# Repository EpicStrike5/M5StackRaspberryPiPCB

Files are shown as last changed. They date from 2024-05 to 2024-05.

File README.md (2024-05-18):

# M5StackRaspberryPiPCB
A simple dev board for using decentralized I/O port from the both of them 

I created this PCB for the sole purpose of decentralizing the I/O port for both the M5Stack Gray and the Raspberry Pi4. The intent is that it's easier to develop on a breadboard with a "fixed" Pi or M5. 

The gist is that we have female header and we decide to populate half of the pin holes ith header. In the case of a 1x2 Header, we solder a 1P header and leaves one hole free so that we can plug rigid cable if we don't want to use jumpers.

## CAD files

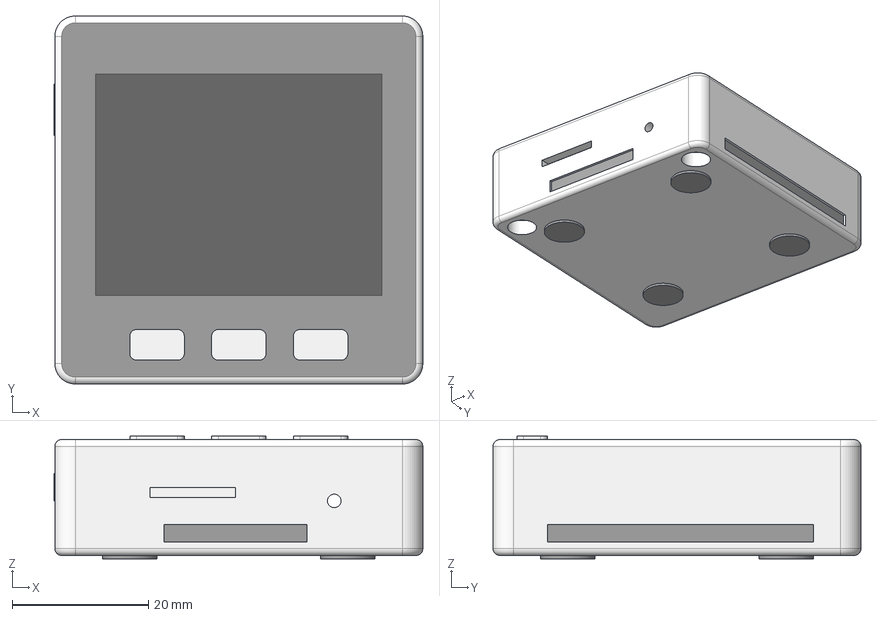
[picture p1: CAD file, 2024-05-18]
Librairie/M5Stack/M5Stack.stp
54.1 x 54.0 x 18.0 mm

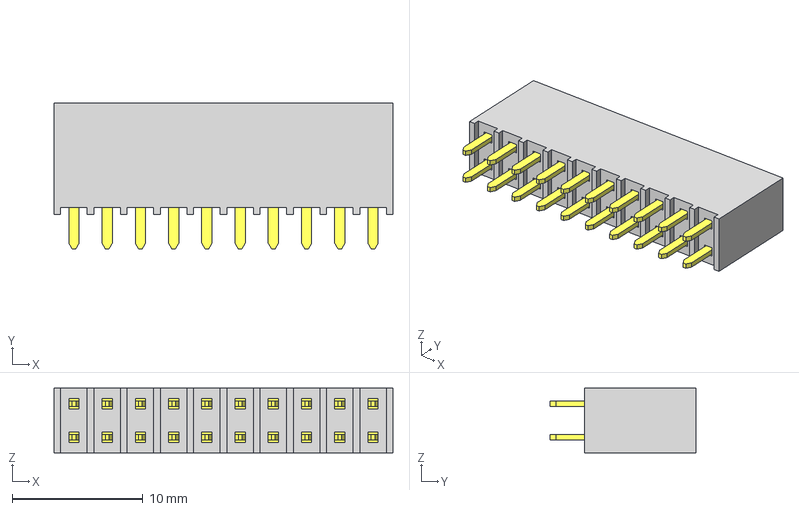
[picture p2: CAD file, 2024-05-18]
Librairie/Pin Header/10Px2/SSW-110-01-L-D.step
25.9 x 11.2 x 4.95 mm
T1SSW-110-01-L-D
P2SSW-110-01-L-D

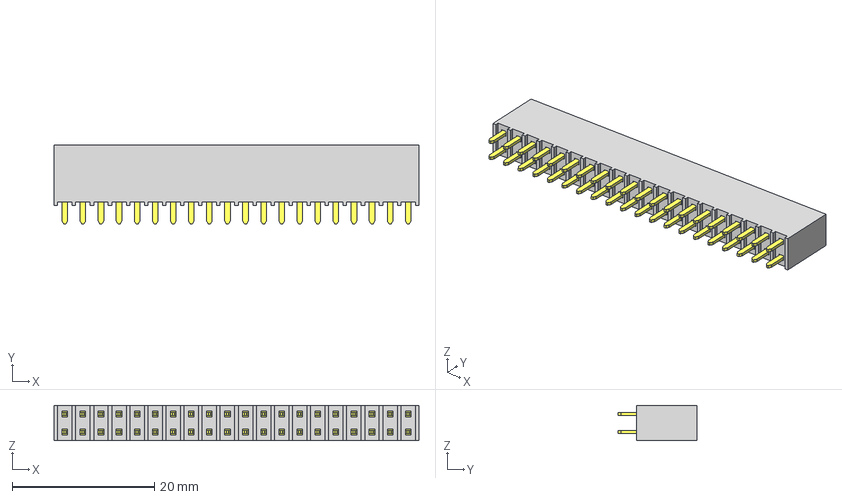
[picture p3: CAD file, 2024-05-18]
Librairie/Pin Header/20X2/SSW-120-01-T-D.step
51.3 x 11.2 x 4.95 mm
T1SSW-120-01-T-D
P2SSW-120-01-T-D

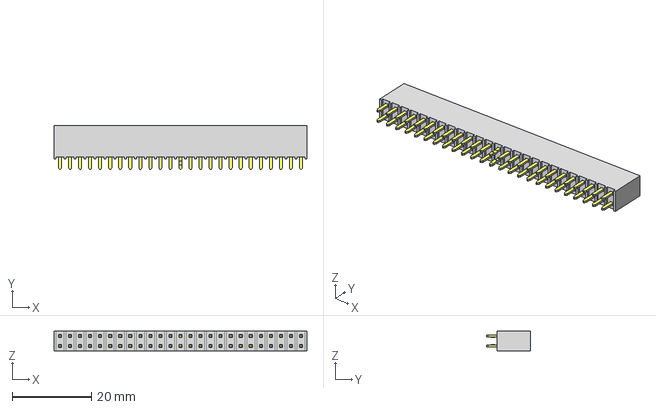
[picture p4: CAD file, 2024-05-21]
Librairie/Pin Header/25x2/SSW-125-01-T-D-LL.step
64.0 x 11.2 x 4.95 mm
T1SSW-125-01-T-D-LL
P2SSW-125-01-T-D-LL

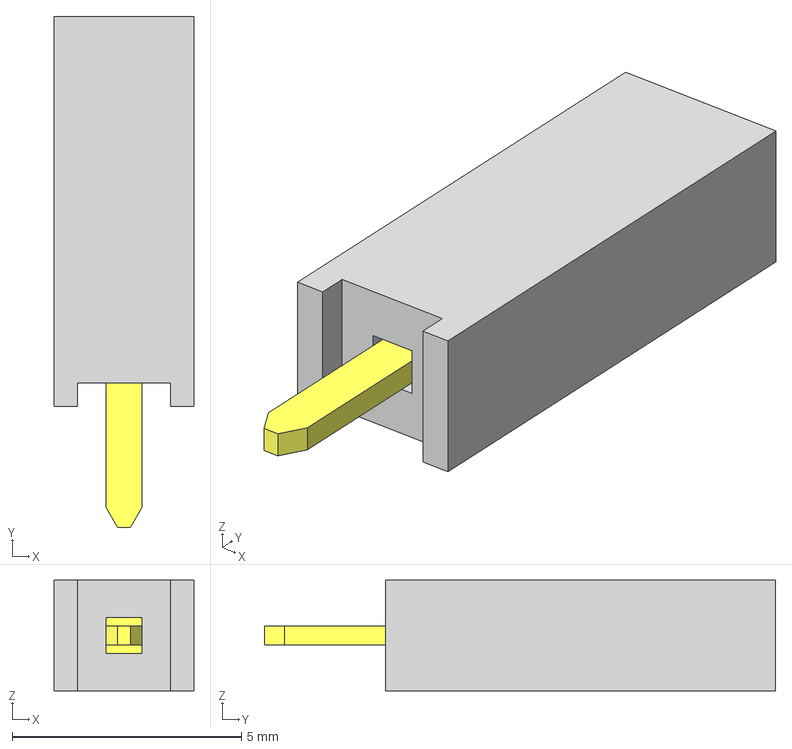
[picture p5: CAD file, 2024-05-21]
Librairie/Pin Header/2P/SSW-101-01-G-S.stp
3.05 x 11.2 x 2.41 mm
T1SSW-101-01-G-S
P2SSW-101-01-G-S

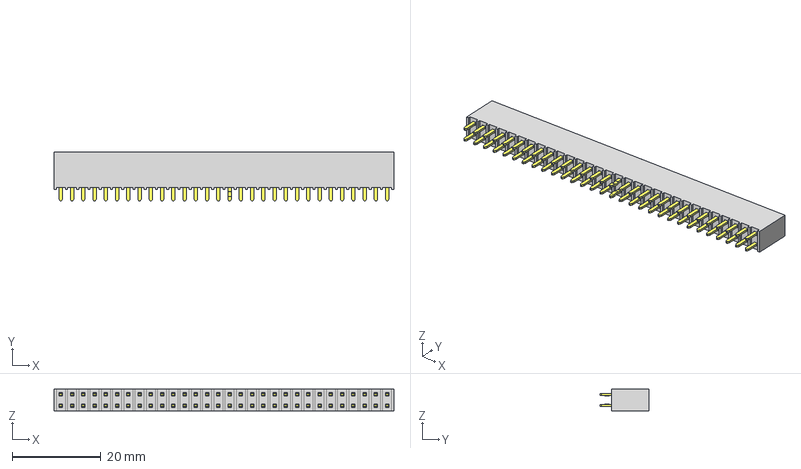
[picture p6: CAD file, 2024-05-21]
Librairie/Pin Header/30x2/SSW-130-01-T-D-LL.step
76.7 x 11.2 x 4.95 mm
T1SSW-130-01-T-D-LL
P2SSW-130-01-T-D-LL

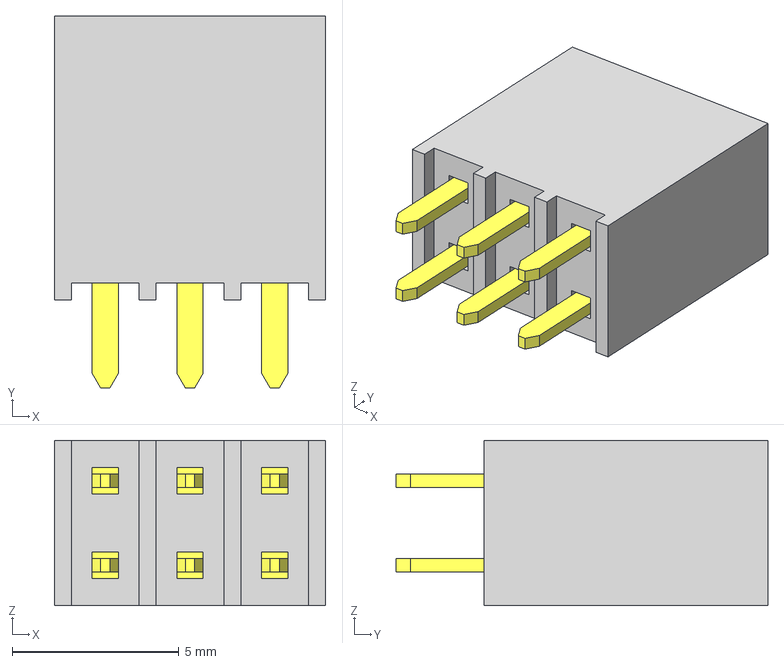
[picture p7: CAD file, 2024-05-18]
Librairie/Pin Header/3Px2/SSW-103-01-T-D.step
8.13 x 11.2 x 4.95 mm
T1SSW-103-01-T-D
P2SSW-103-01-T-D

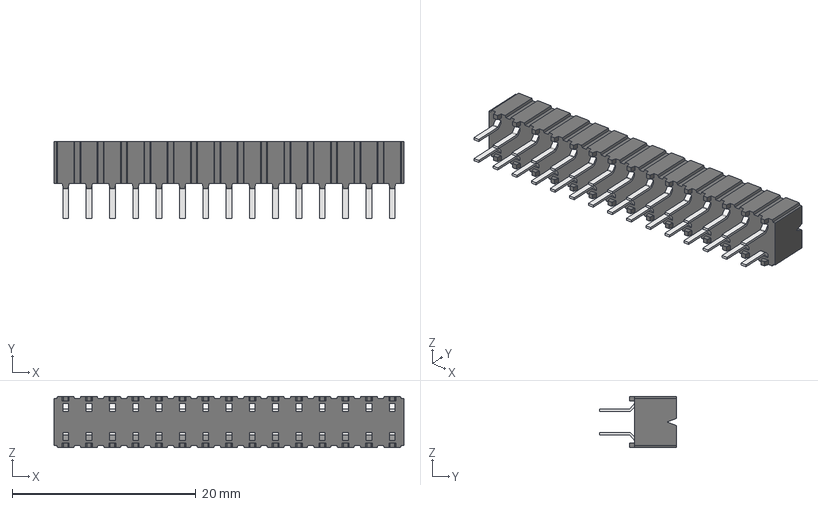
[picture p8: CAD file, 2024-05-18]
Librairie/M5Stack/CES-115-01-T-D.stp
38.1 x 8.33 x 5.59 mm
011501TD2
011501TD
CES-115-01-D_socket

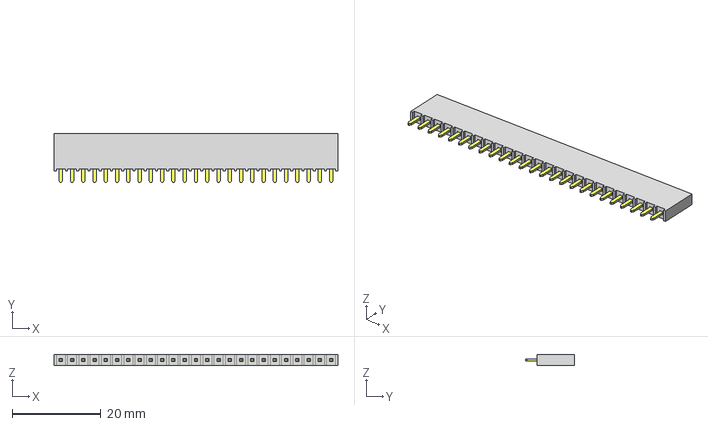
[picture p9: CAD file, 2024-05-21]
Librairie/Pin Header/25x2/SSW-125-01-G-S.stp
64.0 x 11.2 x 2.41 mm
T1SSW-125-01-G-S
P2SSW-125-01-G-S

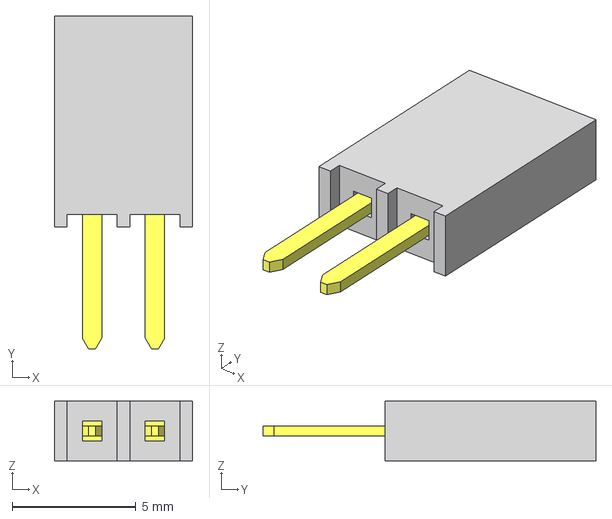
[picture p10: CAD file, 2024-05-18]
Librairie/Pin Header/2P/SSW-102-02-G-S.step
5.59 x 13.4 x 2.41 mm
T1SSW-102-02-G-S
P2SSW-102-02-G-S

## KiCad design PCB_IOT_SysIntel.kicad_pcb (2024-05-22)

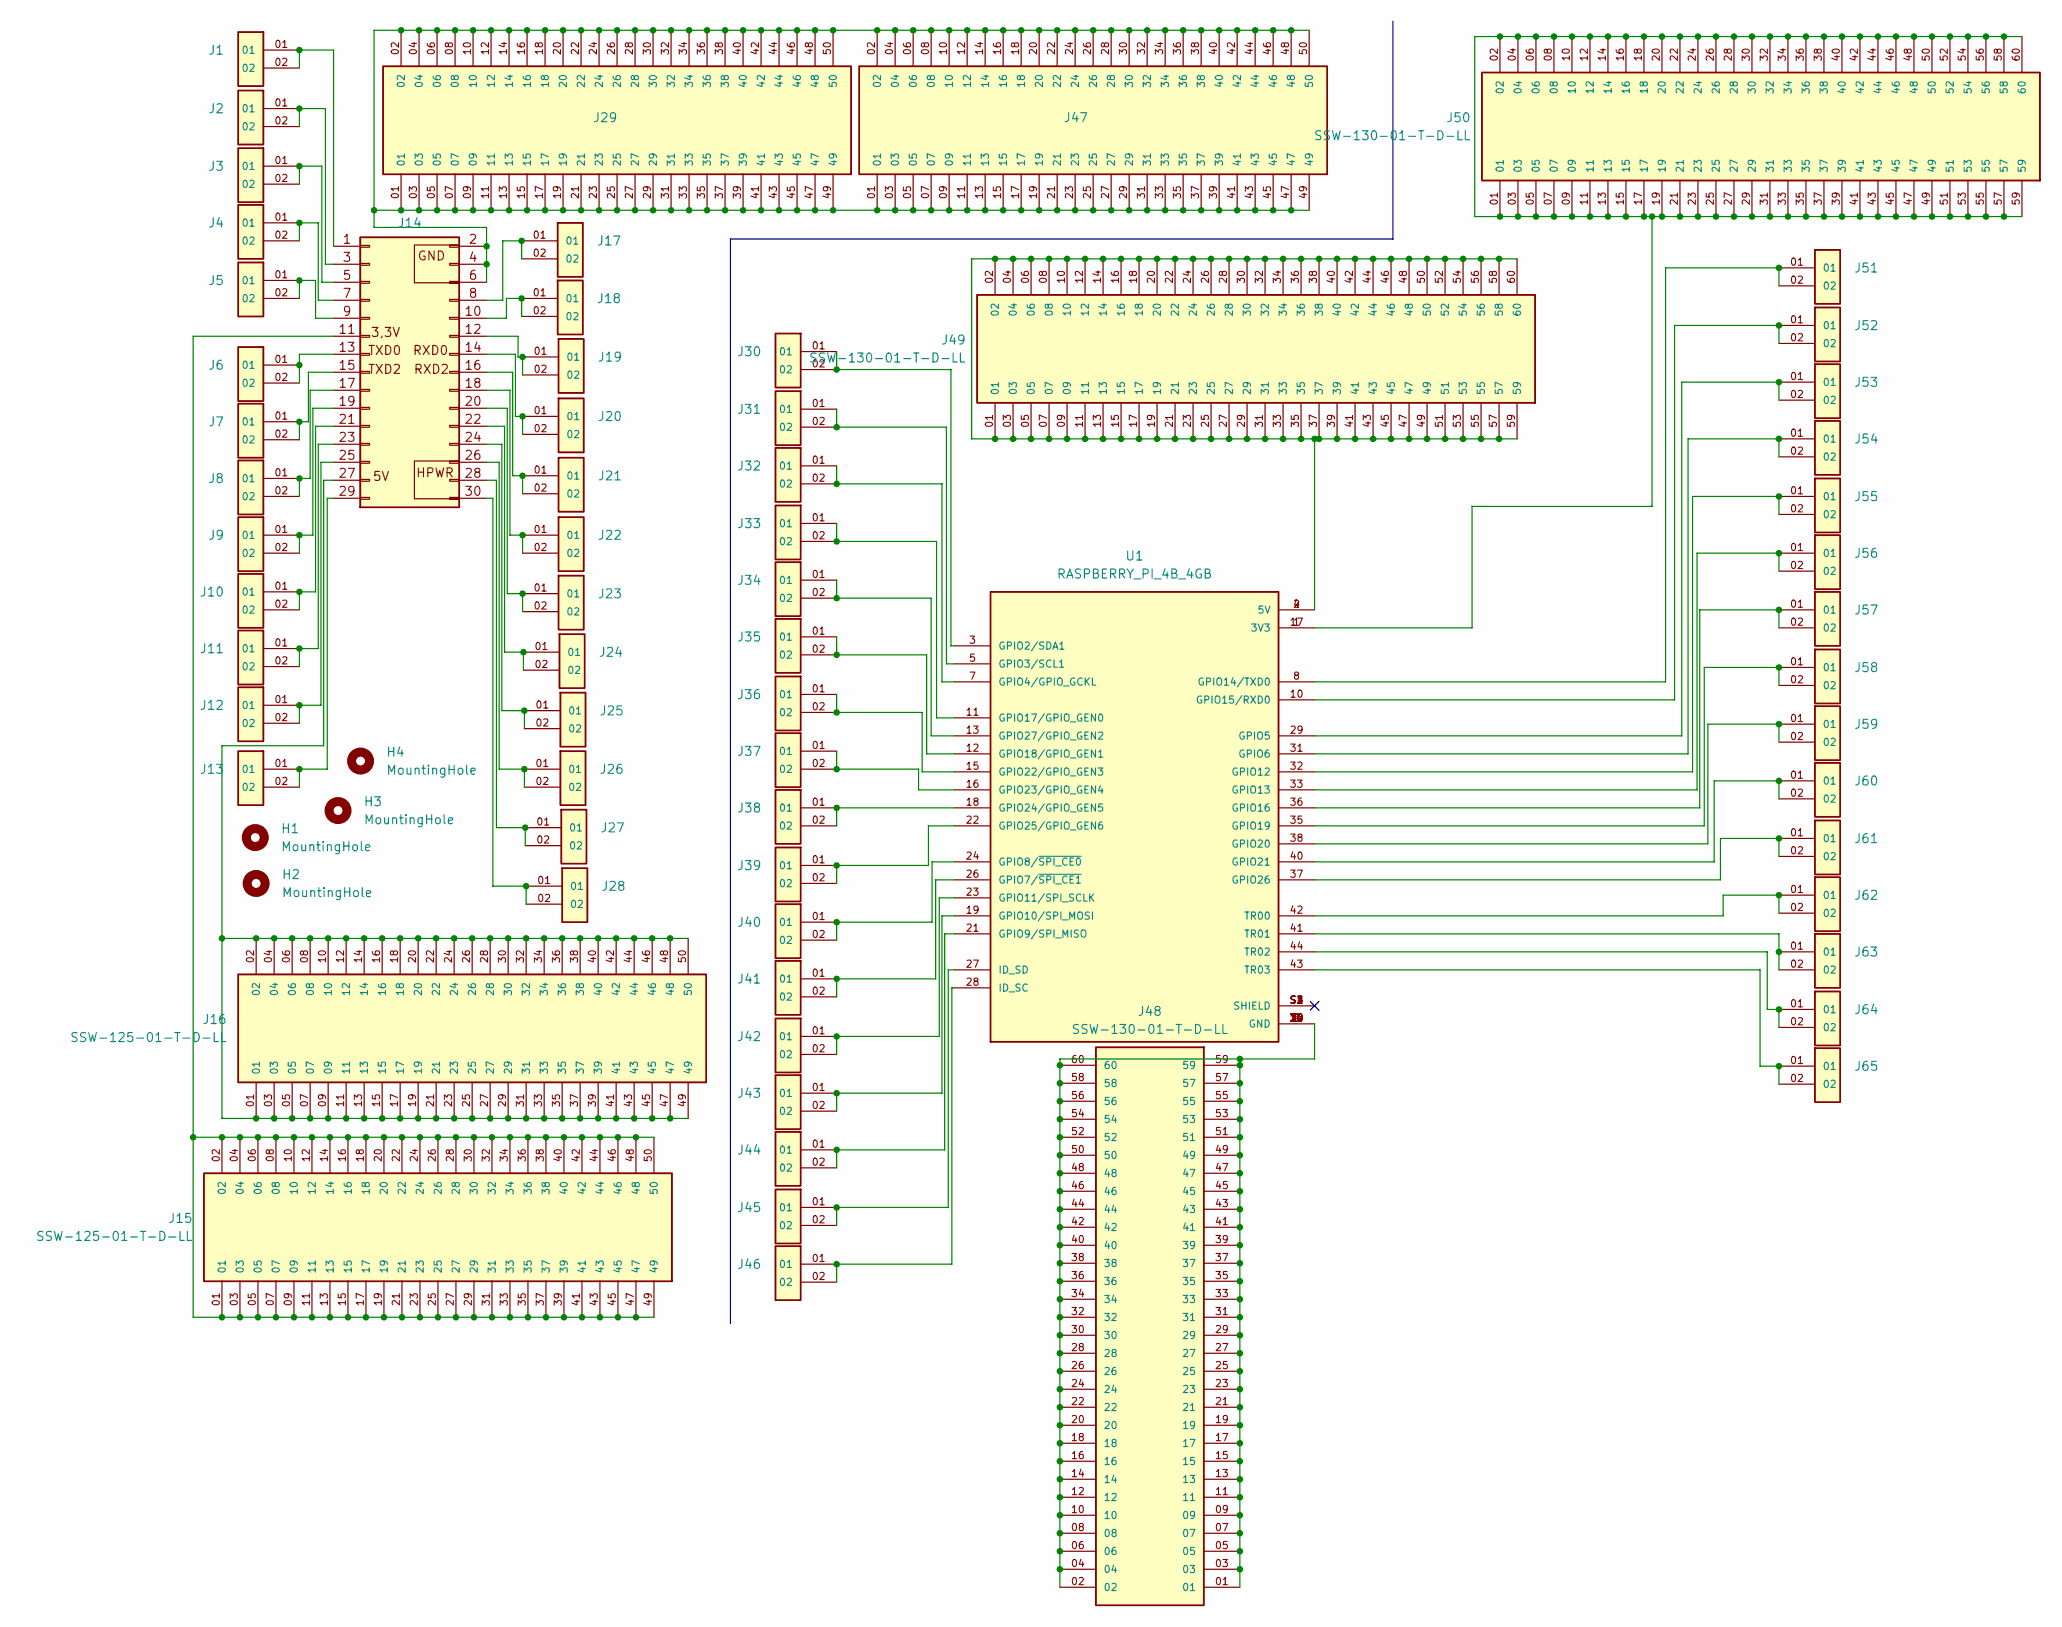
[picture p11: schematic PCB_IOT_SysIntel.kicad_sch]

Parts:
H1, H2, H3, H4: MountingHole; MountingHole_3.2mm_M3
J1, J2, J3, J4, J5, J6, J7, J8, J9, J10, J11, J12, J13, J17, J18, J19, J20, J21, J22, J23, J24, J25, J26, J27, J28, J30, J31, J32, J33, J34, J35, J36, J37, J38, J39, J40, J41, J42, J43, J44, J45, J46, J51, J52, J53, J54, J55, J56, J57, J58, J59, J60, J61, J62, J63, J64, J65: SSW-102-02-G-S; SAMTEC_SSW-102-02-G-S-Populated; PARTREV R
J14: M5Stack
J15, J16, J29: SSW-125-01-T-D-LL; SAMTEC_SSW-125-01-T-D-LL-Populated; PARTREV R
J47: SSW-125-01-T-D-LL; SAMTEC_SSW-125-01-T-D-LL; PARTREV R
J48, J49, J50: SSW-130-01-T-D-LL; SAMTEC_SSW-130-01-T-D-LL; PARTREV R
U1: RASPBERRY_PI_4B_4GB; MODULE_RASPBERRY_PI_4B_4GB; PARTREV 4

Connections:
unnamed: J1.01, J1.02, J14.1
unnamed: J14.2, J14.4, J14.6, J29.01, J29.02, J29.03, J29.04, J29.05, J29.06, J29.07, J29.08, J29.09, J29.10, J29.11, J29.12, J29.13, J29.14, J29.15, J29.16, J29.17, J29.18, J29.19, J29.20, J29.21, J29.22, J29.23, J29.24, J29.25, J29.26, J29.27, J29.28, J29.29, J29.30, J29.31, J29.32, J29.33, J29.34, J29.35, J29.36, J29.37, J29.38, J29.39, J29.40, J29.41, J29.42, J29.43, J29.44, J29.45, J29.46, J29.47, J29.48, J29.49, J29.50, J47.01, J47.02, J47.03, J47.04, J47.05, J47.06, J47.07, J47.08, J47.09, J47.10, J47.11, J47.12, J47.13, J47.14, J47.15, J47.16, J47.17, J47.18, J47.19, J47.20, J47.21, J47.22, J47.23, J47.24, J47.25, J47.26, J47.27, J47.28, J47.29, J47.30, J47.31, J47.32, J47.33, J47.34, J47.35, J47.36, J47.37, J47.38, J47.39, J47.40, J47.41, J47.42, J47.43, J47.44, J47.45, J47.46, J47.47, J47.48, J47.49, J47.50
unnamed: J2.01, J2.02, J14.3
unnamed: J3.01, J3.02, J14.5
unnamed: J4.01, J4.02, J14.7
unnamed: J14.8, J17.01, J17.02
unnamed: J5.01, J5.02, J14.9
unnamed: J14.10, J18.01, J18.02
unnamed: J14.11, J15.01, J15.02, J15.03, J15.04, J15.05, J15.06, J15.07, J15.08, J15.09, J15.10, J15.11, J15.12, J15.13, J15.14, J15.15, J15.16, J15.17, J15.18, J15.19, J15.20, J15.21, J15.22, J15.23, J15.24, J15.25, J15.26, J15.27, J15.28, J15.29, J15.30, J15.31, J15.32, J15.33, J15.34, J15.35, J15.36, J15.37, J15.38, J15.39, J15.40, J15.41, J15.42, J15.43, J15.44, J15.45, J15.46, J15.47, J15.48, J15.49, J15.50
unnamed: J14.12, J19.01, J19.02
unnamed: J6.01, J6.02, J14.13
unnamed: J14.14, J20.01, J20.02
unnamed: J7.01, J7.02, J14.15
unnamed: J14.16, J21.01, J21.02
unnamed: J8.01, J8.02, J14.17
unnamed: J14.18, J22.01, J22.02
unnamed: J9.01, J9.02, J14.19
unnamed: J14.20, J23.01, J23.02
unnamed: J10.01, J10.02, J14.21
unnamed: J14.22, J24.01, J24.02
unnamed: J11.01, J11.02, J14.23
unnamed: J14.24, J25.01, J25.02
unnamed: J12.01, J12.02, J14.25
unnamed: J14.26, J26.01, J26.02
unnamed: J14.27, J16.01, J16.02, J16.03, J16.04, J16.05, J16.06, J16.07, J16.08, J16.09, J16.10, J16.11, J16.12, J16.13, J16.14, J16.15, J16.16, J16.17, J16.18, J16.19, J16.20, J16.21, J16.22, J16.23, J16.24, J16.25, J16.26, J16.27, J16.28, J16.29, J16.30, J16.31, J16.32, J16.33, J16.34, J16.35, J16.36, J16.37, J16.38, J16.39, J16.40, J16.41, J16.42, J16.43, J16.44, J16.45, J16.46, J16.47, J16.48, J16.49, J16.50
unnamed: J14.28, J27.01, J27.02
unnamed: J13.01, J13.02, J14.29
unnamed: J14.30, J28.01, J28.02
unnamed: J48.01, J48.02, J48.03, J48.04, J48.05, J48.06, J48.07, J48.08, J48.09, J48.10, J48.11, J48.12, J48.13, J48.14, J48.15, J48.16, J48.17, J48.18, J48.19, J48.20, J48.21, J48.22, J48.23, J48.24, J48.25, J48.26, J48.27, J48.28, J48.29, J48.30, J48.31, J48.32, J48.33, J48.34, J48.35, J48.36, J48.37, J48.38, J48.39, J48.40, J48.41, J48.42, J48.43, J48.44, J48.45, J48.46, J48.47, J48.48, J48.49, J48.50, J48.51, J48.52, J48.53, J48.54, J48.55, J48.56, J48.57, J48.58, J48.59, J48.60, U1.6 (GND), U1.9 (GND), U1.14 (GND), U1.20 (GND), U1.25 (GND), U1.30 (GND), U1.34 (GND), U1.39 (GND)
unnamed: J49.01, J49.02, J49.03, J49.04, J49.05, J49.06, J49.07, J49.08, J49.09, J49.10, J49.11, J49.12, J49.13, J49.14, J49.15, J49.16, J49.17, J49.18, J49.19, J49.20, J49.21, J49.22, J49.23, J49.24, J49.25, J49.26, J49.27, J49.28, J49.29, J49.30, J49.31, J49.32, J49.33, J49.34, J49.35, J49.36, J49.37, J49.38, J49.39, J49.40, J49.41, J49.42, J49.43, J49.44, J49.45, J49.46, J49.47, J49.48, J49.49, J49.50, J49.51, J49.52, J49.53, J49.54, J49.55, J49.56, J49.57, J49.58, J49.59, J49.60, U1.2 (5V), U1.4 (5V)
unnamed: J50.01, J50.02, J50.03, J50.04, J50.05, J50.06, J50.07, J50.08, J50.09, J50.10, J50.11, J50.12, J50.13, J50.14, J50.15, J50.16, J50.17, J50.18, J50.19, J50.20, J50.21, J50.22, J50.23, J50.24, J50.25, J50.26, J50.27, J50.28, J50.29, J50.30, J50.31, J50.32, J50.33, J50.34, J50.35, J50.36, J50.37, J50.38, J50.39, J50.40, J50.41, J50.42, J50.43, J50.44, J50.45, J50.46, J50.47, J50.48, J50.49, J50.50, J50.51, J50.52, J50.53, J50.54, J50.55, J50.56, J50.57, J50.58, J50.59, J50.60, U1.1 (3V3), U1.17 (3V3)
unnamed: J30.01, J30.02, U1.3 (GPIO2/SDA1)
unnamed: J31.01, J31.02, U1.5 (GPIO3/SCL1)
unnamed: J32.01, J32.02, U1.7 (GPIO4/GPIO_GCKL)
unnamed: J53.01, J53.02, U1.29 (GPIO5)
unnamed: J54.01, J54.02, U1.31 (GPIO6)
unnamed: J41.01, J41.02, U1.26 (GPIO7/~SPI_CE1)
unnamed: J40.01, J40.02, U1.24 (GPIO8/~SPI_CE0)
unnamed: J44.01, J44.02, U1.21 (GPIO9/SPI_MISO)
unnamed: J43.01, J43.02, U1.19 (GPIO10/SPI_MOSI)
unnamed: J42.01, J42.02, U1.23 (GPIO11/SPI_SCLK)
unnamed: J55.01, J55.02, U1.32 (GPIO12)
unnamed: J56.01, J56.02, U1.33 (GPIO13)
unnamed: J51.01, J51.02, U1.8 (GPIO14/TXD0)
unnamed: J52.01, J52.02, U1.10 (GPIO15/RXD0)
unnamed: J57.01, J57.02, U1.36 (GPIO16)
unnamed: J33.01, J33.02, U1.11 (GPIO17/GPIO_GEN0)
unnamed: J35.01, J35.02, U1.12 (GPIO18/GPIO_GEN1)
unnamed: J58.01, J58.02, U1.35 (GPIO19)
unnamed: J59.01, J59.02, U1.38 (GPIO20)
unnamed: J60.01, J60.02, U1.40 (GPIO21)
unnamed: J36.01, J36.02, U1.15 (GPIO22/GPIO_GEN3)
unnamed: J37.01, J37.02, U1.16 (GPIO23/GPIO_GEN4)
unnamed: J38.01, J38.02, U1.18 (GPIO24/GPIO_GEN5)
unnamed: J39.01, J39.02, U1.22 (GPIO25/GPIO_GEN6)
unnamed: J61.01, J61.02, U1.37 (GPIO26)
unnamed: J34.01, J34.02, U1.13 (GPIO27/GPIO_GEN2)
unnamed: J46.01, J46.02, U1.28 (ID_SC)
unnamed: J45.01, J45.02, U1.27 (ID_SD)
unnamed: J62.01, J62.02, U1.42 (TR00)
unnamed: J63.01, J63.02, U1.41 (TR01)
unnamed: J64.01, J64.02, U1.44 (TR02)
unnamed: J65.01, J65.02, U1.43 (TR03)

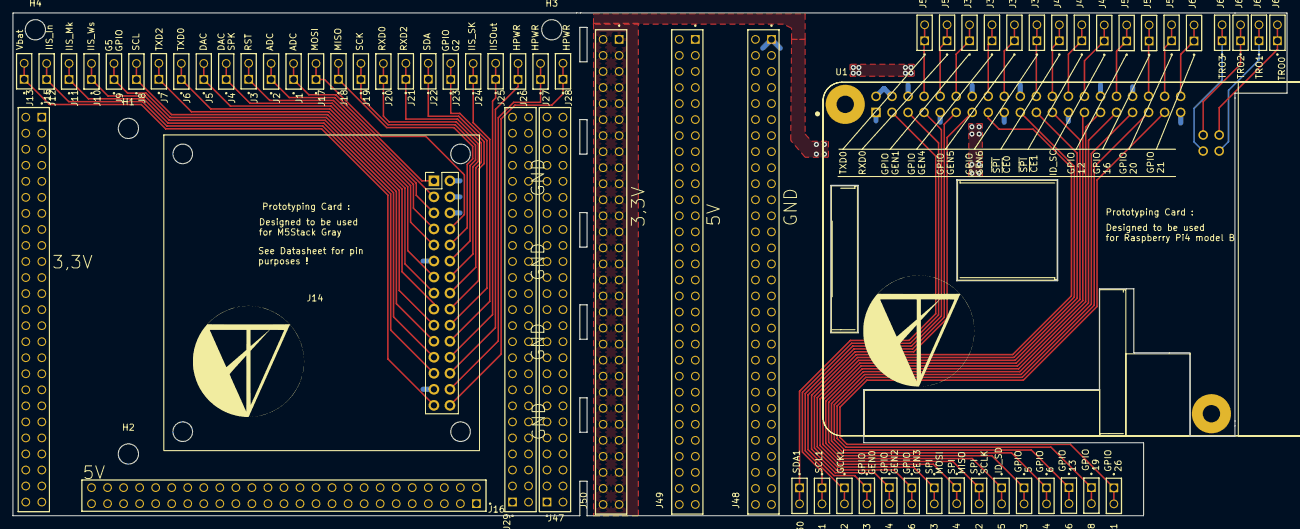
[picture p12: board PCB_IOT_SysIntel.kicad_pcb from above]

Board: 2 copper layers, 201.8 x 79.6 mm, 70 parts (0 on the bottom side), 63 nets.

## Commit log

2024-05-18 First Commit :
    Created libraries with header
    [CES-115-01-T-D.stp, M5Stack.stp, PCB_IOT_SysIntel.kicad_pcb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]
2024-05-21 Project Version 1 Completed
    [PCB_IOT_SysIntel-B_Cu.gbl, PCB_IOT_SysIntel-B_Mask.gbs, PCB_IOT_SysIntel-B_Paste.gbp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]
2024-05-22 Fixed Mounting hole issues
    [PCB_IOT_SysIntel-B_Cu.gbl, PCB_IOT_SysIntel-B_Mask.gbs, PCB_IOT_SysIntel-B_Paste.gbp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]

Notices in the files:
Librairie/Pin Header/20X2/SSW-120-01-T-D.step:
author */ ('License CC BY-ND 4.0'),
